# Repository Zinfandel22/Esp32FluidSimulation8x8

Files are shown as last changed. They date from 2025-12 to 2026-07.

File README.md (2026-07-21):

# esp32-s3-flip-fluid-simulation
FLIP (+ PIC) fluid simulation on ESP32-S3 with 8x8 LED matrix display and accelerometer-controlled gravity.

Main objective is to implement a particle-based fluid dynamics simulation using the FLIP method on embedded hardware, exploring the challenges of real-time physics calculations with limited computational resources while creating an interactive, visually appealing display.

## Table of Contents
- [Hardware Components](#hardware-components)
- [Assembly](#assembly)
- [Pinout Configuration](#pinout-configuration)
- [Physical Setup](#physical-setup)
- [Key Features](#key-features)
  - [FLIP Fluid Simulation](#flip-fluid-simulation)
  - [Incompressibility Solver](#incompressibility-solver)
  - [Particle Dynamics Pipeline](#particle-dynamics-pipeline)
  - [Spatial Hash Grid](#spatial-hash-grid)
  - [Bilinear Interpolation](#bilinear-interpolation)
  - [Button Control System](#button-control-system)
  - [Color Presets](#color-presets)
  - [Visualization](#visualization)
  - [Accelerometer Integration](#accelerometer-integration)
- [Technical Specifications](#technical-specifications)
  - [Performance](#performance)
  - [Memory Usage](#memory-usage)
  - [Compiler Optimizations](#compiler-optimizations)
- [Algorithm Details](#algorithm-details)
  - [FLIP Method](#flip-method)
  - [Pressure Projection](#pressure-projection)
  - [Particle Collision](#particle-collision)
- [Build Environment](#build-environment)
- [Configuration Options](#configuration-options)
- [Usage](#usage)
- [Credit](#credit)
- [License](#license)

## Hardware Components
- Waveshare ESP32-S3-Matrix Development Board with 8x8 led matrix and QMI8658 6-Axis IMU (Accelerometer + Gyroscope) integrated
- Momentary Push Button
- Small switch
- TP4057 1A
- 220mAh Lipo pouch battery
hardwareComponents

## Assembly

### Solder de components together using AWG30 wires
guts

### Design and print the casing
casing

### Place the components in casing
gutsincasing

### Finished product
finished2

## Pinout Configuration

### NeoPixel LED Matrix
```cpp
LED_PIN = GPIO 14   // WS2812B data line
NUM_LEDS = 64       // 8x8 matrix
```

### QMI8658 IMU (I2C)
```cpp
SDA_PIN = GPIO 11   // I2C data
SCL_PIN = GPIO 12   // I2C clock
QMI8658_ADDR = 0x6B // I2C device address
I2C_FREQ = 400kHz   // fast mode
```

### Control Button
```cpp
BUTTON_PIN = GPIO 5  // user input (with internal pullup)
```

Button is active low (pressed = LOW, released = HIGH)

## Physical Setup
The simulation uses a 500mm x 500mm virtual container. Particles are constrained inside the solid simulation boundary, and the reachable fluid area is mapped across the full 8x8 LED grid for display. The LED matrix serves as a low-resolution display. The QMI8658 accelerometer continuously updates the gravity direction, allowing the fluid to respond naturally to device orientation.

## Key Features

### FLIP Fluid Simulation

(* means configurable as parameter in config.h)
Particle-In-Cell hybrid method combining Lagrangian particles with Eulerian grid:
- **400 Particles:** hexagonally packed for optimal density, radius = 0.3 * cell_size(*)
- **20x20 Simulation Grid:** provides velocity field for incompressibility solving(*)
- **FLIP/PIC Blending:** 94% FLIP + 6% PIC for stability while preserving momentum(*)
- **Frame Interval:** 23ms real-time (43.5 fps target)(*)
- **Physics Timestep:** 27.6ms simulated time per frame (1.2x speed multiplier snappier fluid motion)(*)
- **Gravity Magnitude:** 9.81 m/s^2, direction updated from accelerometer each frame(*)

### Incompressibility Solver
Iterative pressure projection using Gauss-Seidel with successive over-relaxation:
- **15 Iterations:** balances accuracy vs. computation time (~1.5ms solve time)(*)
- **Over-Relaxation Factor:** 1.9x to accelerate convergence(*)
- **Density Correction:** compensates for particle drift using K-factor = 1.0(configurable)(*)
- **Grid Classification:** cells marked as LIQUID, AIR, or WALL based on particle occupancy

### Particle Dynamics Pipeline
Nine-stage FLIP cycle executed each frame:
1. **Integration:** apply gravity, update positions based on velocity
2. **Separation:** push overlapping particles apart (2 iterations, spatial hash grid)
3. **Collision:** clamp particles inside boundaries with restitution/friction
4. **Grid Preparation:** reset cell types, mark liquid cells, save previous velocities
5. **Particle → Grid Transfer:** scatter particle velocities to grid using bilinear weights
6. **Normalization:** divide accumulated velocities by weights, restore wall velocities
7. **Density Calculation:** compute particle density per cell for drift compensation
8. **Incompressibility Solve:** iteratively adjust velocities to minimize divergence
9. **Grid → Particle Transfer:** interpolate corrected velocities back to particles with FLIP/PIC blending

### Spatial Hash Grid
Efficient particle separation using uniform grid acceleration structure:
- **Cell Spacing:** 2.2 × particle_radius for optimal bucket size
- **Initial Packing:** particles initialized at 1.8 × radius spacing (tighter than 2.0) to increase rest density
- **Collision Detection:** only checks particles in same/adjacent cells (9 cells total)
- **Separation Force:** pushes particles to minimum separation distance
- **Memory Layout:** flat arrays (num_cell_particles, first_cell_particle, cell_particle_ids)
- Significantly faster than O(n²) all-pairs check for 400 particles

### Bilinear Interpolation
Smooth velocity transfers between particles and staggered MAC grid:
- **Staggered Grid:** vx stored on vertical faces, vy on horizontal faces
- **4-Point Weights:** precomputed for each particle based on position
- **Sub-Cell Accuracy:** particles can be anywhere within cell, not just at centers
- **Weight Accumulation:** prevents velocity discontinuities at cell boundaries
- Computed once per particle per transfer, reused for both velocity components

### Button Control System
State machine with debouncing for three interaction types:
- **Single Tap (< 600ms):** cycle through 7 brightness levels (3-13 intensity)(*)
- **Double Tap (< 250ms between):** cycle through 17 color presets (blues, greens, reds, yellows, purples, pinks, white)(*)
- **Long Press (≥ 600ms):** cycle through 5 foam threshold levels (2-30 particle count)(*)
- **Debouncing:** 25ms settling time eliminates mechanical noise(*)
- **NVS Persistence:** settings saved to flash immediately after change, restored on boot

### Color Presets
17 carefully tuned color combinations optimized for LED visibility:
- **Blues/Cyans (4):** pure blue, cyan, sky blue, aqua
- **Greens (2):** lime green, yellow-green
- **Reds (2):** pure red, crimson
- **Oranges/Yellows (3):** orange, golden yellow, amber
- **Purples (3):** violet, lavender, deep purple
- **Pinks/Magentas (2):** hot pink, magenta
- **White (1):** full spectrum white

Each preset is scaled by current brightness setting (0-255 range)

### Visualization
Particle density mapping to LED colors with foam effect:
- **Liquid Rendering:** LEDs with intensity above 2.0 show fluid color at current brightness(*)
- **Foam Effect:** LEDs above the current foam threshold display white at 30% brightness(*)
- **Brightness Scaling:** base color RGB values multiplied by brightness factor (3-13)(*)
- **LED Smoothing:** particles are bilinearly splatted into neighboring LEDs with 0.60 frame persistence(*)
- **Update Rate:** 23ms target frame interval (~43.5 fps), with measured compute headroom up to ~122 fps
- Physical-to-pixel mapping: reachable particle region (meters) -> LED coordinates (0-7)

### Accelerometer Integration
Real-time gravity direction from QMI8658 6-axis IMU:
- **Sensor Mode:** accelerometer only (gyroscope disabled for efficiency)
- **Update Frequency:** every frame (~43 Hz)
- **Range:** ±4g with 8192 LSB/g sensitivity
- **Axis Mapping:** device Y-axis → simulation X (horizontal), device X-axis → simulation Y (vertical)
- **Magnitude:** constant 9.81 m/s², direction varies with tilt
- **Response:** fluid immediately reacts to device orientation changes
- **Calibration:** automatic via sensor hardware, no user calibration needed

## Technical Specifications

### Performance
- **Simulation Grid:** 20x20 cells (400 total)
- **Display Grid:** 8x8 LEDs (64 total, low-resolution fluid projection)
- **Particle Count:** 400 active particles
- **Frame Interval:** 23ms target (43.5 fps)
- **Measured Compute Headroom:** 8.16ms total frame time (~122.5 fps theoretical max)
- **Frame Breakdown:**
  - Integration: ~0.02ms
  - Separation: ~2.40ms
  - Collision: ~0.11ms
  - Grid Prep: ~0.18ms
  - P->G Transfer: ~0.55ms
  - Density: ~0.21ms
  - Solver: ~1.53ms
  - G->P Transfer: ~1.00ms
  - Visualization: ~2.16ms
  - **Total:** ~8.16ms per frame

### Memory Usage
- **Particle Array:** 400 * 16 bytes = 6.4 KB
- **Grid Velocities:** 4 * 400 * 4 bytes = 6.4 KB (current + previous)
- **Weight Accumulators:** 2 * 400 * 4 bytes = 3.2 KB
- **Cell Types:** 400 cells
- **Spatial Hash:** ~9 KB (particle bucketing)
- **Density Array:** 400 * 4 bytes = 1.6 KB
- **Liquid Cell List:** 400 * 4 bytes = 1.6 KB
- **Total:** ~30 KB for the main simulation arrays

### Compiler Optimizations
Aggressive optimization flags for maximum performance:
- **-O3:** maximum optimization level
- **-ffast-math:** aggressive floating-point optimizations (IEEE compliance relaxed)
- **-funroll-loops:** unroll loops for better pipelining
- **-fomit-frame-pointer:** free up register for computations
- **CPU Frequency:** 240 MHz (maximum ESP32-S3 speed)
- **Flash Frequency:** 80 MHz for fast code fetching

## Algorithm Details

Implemented following Ten Minute Physics tutorial closely (https://www.youtube.com/watch?v=XmzBREkK8kY)

### FLIP Method
- **Particles:** carry velocity and position, no pressure field
- **Grid:** solves for incompressibility, enforces boundary conditions
- **Transfer P→G:** particles scatter velocities to grid with bilinear interpolation
- **Solve Pressure:** grid velocities adjusted to satisfy â‹…u = 0
- **Transfer G→P:** particles updated with FLIP/PIC blend:
  - **PIC (6%):** vnew = vgrid (dissipative, stable)
  - **FLIP (94%):** vnew = vold + (vgrid - vgrid_old) (preserves momentum)

### Pressure Projection
- **Divergence Calculation:** sum of velocity flux through cell faces
- **Pressure Gradient:** distributes correction to neighboring cells
- **Over-Relaxation:** scales correction by 1.9x to accelerate convergence
- **Boundary Conditions:** solid walls have zero normal velocity
- **Density Compensation:** adds drift correction term based on particle deficit/surplus

### Particle Collision
Handles boundaries with configurable restitution and friction:
- **Wall Detection:** clamp position one simulation cell plus particle_radius inside the domain
- **Restitution Factor:** 0.2 (20% velocity preserved on bounce)(*)
- **Friction Factor:** 0.2 (20% tangential velocity preserved)(*)
- **Clamping:** prevents particles from penetrating walls
- Applied after position update, before grid transfer

## Build Environment

### PlatformIO Configuration
```ini
[env:esp32-s3-matrix]
platform = espressif32
board = esp32-s3-devkitc-1
framework = arduino

; CRITICAL: Flash configuration for ESP32-S3-Matrix
board_build.flash_mode = dio
board_build.flash_size = 4MB
board_build.partitions = default.csv
board_upload.flash_size = 4MB

; 1. Hardware Accelerations
board_build.f_cpu = 240000000L
board_build.f_flash = 80000000L

build_flags = 
    -DARDUINO_USB_CDC_ON_BOOT=1
    ; compiler optimizations
    -O3
    -ffast-math
    -funroll-loops
    -fomit-frame-pointer
    ; disable debug overhead
    -DCORE_DEBUG_LEVEL=0
    
monitor_speed = 115200
upload_speed = 921600

lib_deps = 
    adafruit/Adafruit NeoPixel@^1.12.0
```

Flash mode and size are pinned explicitly since this board's flash chip isn't always autodetected correctly; the partition table uses PlatformIO's standard `default.csv` scheme.

## Configuration Options

All simulation parameters can be adjusted in `config.h`:

### Physics Constants
```cpp
GRAVITY_MAGNITUDE = 9.81f          // m/s²
FRAME_INTERVAL = 0.023f            // base timestep
SPEED_MULTIPLIER = 1.2f            // time acceleration
FLIP_RATIO = 0.94f                 // FLIP vs PIC blend
INCOMPRESSIBILITY_ITERATIONS = 15  // solver iterations
OVERRELAXATION = 1.9f              // convergence acceleration
```

### Particle Settings
```cpp
NUM_PARTICLES = 400                // total particle count
RESTITUTION_FACTOR = 0.2f          // bounce coefficient
FRICTION_FACTOR = 0.2f             // wall friction
```

### Grid Resolution
```cpp
GRID_SIZE_X = 20                   // simulation cells
GRID_SIZE_Y = 20
PHYSICAL_WIDTH = 0.5f              // meters
PHYSICAL_HEIGHT = 0.5f
```

### Visualization
```cpp
PARTICLE_THRESHOLD = 2.0f          // min LED intensity for liquid color
LED_PERSISTENCE = 0.60f            // display smoothing decay
// Foam thresholds: 30, 5, 4, 3, 2  // configured in button presets
```

## Usage

### First Boot
1. Device initializes with default settings (blue color, low brightness, low foam)
2. Particles appear in block formation at bottom of display
3. Tilt device to control gravity direction - fluid responds immediately
### Test

https://github.com/user-attachments/assets/9a86d0c9-9984-4224-b226-0375ce9b3e63

### Button Controls
- **Single Tap:** cycle brightness (3 → 4 → 5 → 6 → 9 → 11 → 13 → 3...)
- **Double Tap:** cycle colors (blue → cyan → green → red → orange → purple → pink → white → blue...)
- **Long Press:** cycle foam threshold (none → low → medium → high → max → none...)
### Button funcionality test

https://github.com/user-attachments/assets/5af7af76-c64d-4482-b536-27835820dfac

### Settings Persistence
All button settings automatically save to flash and restore on next power-up.

## Credit

- MAtthias Müller´s Ten Minute Physics: "18 - How to write a FLIP water / fluid simulation running in your browser"
- https://www.youtube.com/watch?v=XmzBREkK8kY

## License
MIT License - feel free to use, modify, and distribute.

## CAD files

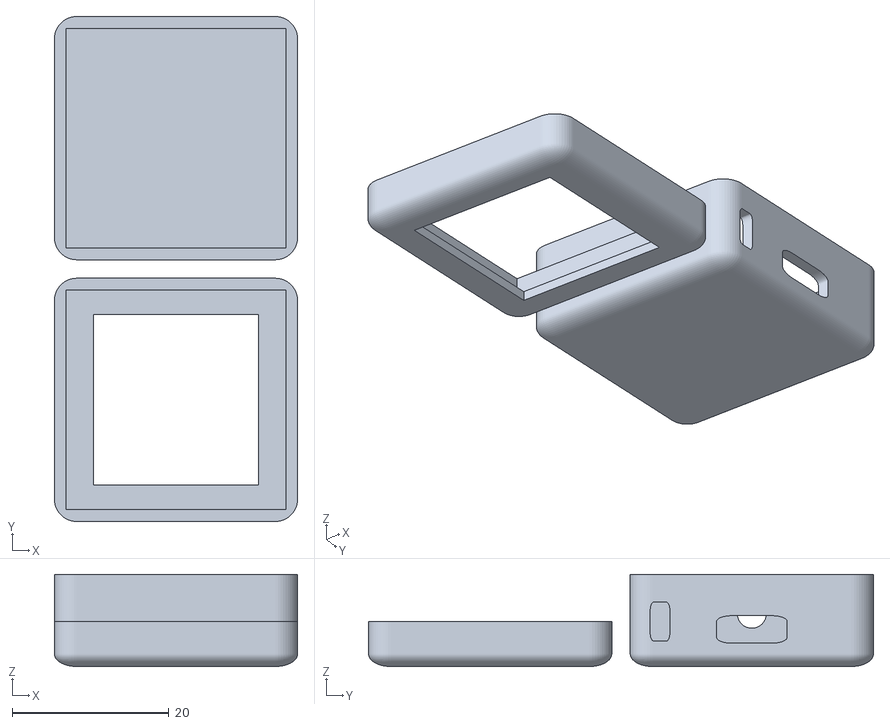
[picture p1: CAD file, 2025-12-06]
Casing and box/2D8x8fluidcasing.stl
31.0 x 64.3 x 11.7

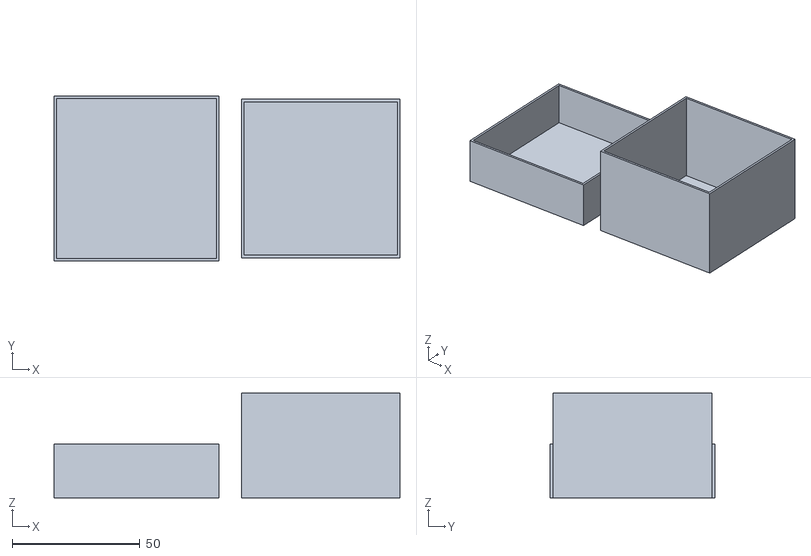
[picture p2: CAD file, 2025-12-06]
Casing and box/giftbox.stl
135.2 x 64.5 x 41.0

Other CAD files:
Casing and box/2D8x8fluidcasing.blend
Casing and box/giftbox.blend

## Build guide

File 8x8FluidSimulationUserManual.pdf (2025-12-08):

# 8×8 LED Matrix Mini Fluid Simulation Gadget

## User Manual

## Device Overview

FLIP Fluid Simulator with a real-time physics simulation displayed on a 64-LED matrix (8×8 grid) at ~43 FPS (23ms per frame). The built-in accelerometer allows the fluid to respond to device tilting.

## Button Controls

The device features a single button with three press patterns:

Gesture | Action
Single Press | Cycle through 7 brightness levels (3, 4, 5, 6, 9, 11, 13)
Double-Press | Cycle through 17 color presets (blues, greens, reds, oranges, yellows, purples, pinks, white)
Long Press | Hold 600ms to cycle foam effect threshold (5 levels)

Note: Colors are mixed from RGB (0–255) then compressed to brightness level. Some colors may look identical at low brightness (e.g. at level 3: BLUE1 (0,0,255) → (0,0,3) and PURPLE1 (60,0,255) → (0,0,3)).

## Technical Specifications

Component | Specification
Microcontroller | ESP32-S3 @ 240MHz
Display | 64 RGB LEDs (8×8 matrix, WS2812B)
Accelerometer | QMI8658 6-axis IMU
Power | 220mAh LiPo battery

# Open Source Project

Full source code available at:

### github.com/vateva/Esp328x8fluid

Built with:
ESP32-S3 | FreeRTOS | C/C++ | FLIP Fluid Simulation
QMI8658 IMU | WS2812B LED Matrix

© 2025 - Open Source Hardware & Software Licensed under MIT License

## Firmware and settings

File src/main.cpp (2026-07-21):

#include "config.h"
#include "grid.h"
#include "particle.h"
#include "utils.h"
#include "button.h"

#include <WiFi.h>
#include <esp_bt.h>
#include <esp_wifi.h>

#include "esp_sleep.h"

// global instances
Adafruit_NeoPixel matrix = Adafruit_NeoPixel(NUM_LEDS, LED_PIN, NEO_RGB + NEO_KHZ800);
Grid grid;                         // single grid instance for the simulation
Particle particles[NUM_PARTICLES]; // array of all particles
ButtonHandler button;              // button

// timing control for fixed timestep
unsigned long lastStepTime = 0;

// gravity vector (updated from accelerometer each frame)
float gravityX = 0.0f;
float gravityY = -GRAVITY_MAGNITUDE; // default: pointing down
float currentAccelZ = 0.0f;          // ADD THIS: To track face-down state

// particle radius - calculated from cell size like reference code
float particleRadius = 0.0f;

// LED intensity buffers. Particles are splatted into the 8x8 display with
// bilinear weights, then lightly decayed to hide 8x8 quantization.
float ledIntensity[NUM_LEDS] = {0.0f};
float ledNextIntensity[NUM_LEDS] = {0.0f};

// --- Profiling Variables (Time in milliseconds) ---
float t_integrate = 0; // Movement & Gravity
float t_push = 0;      // Particle Separation (Heavy)
float t_collision = 0; // Wall handling
float t_grid_prep = 0; // Resetting/Clearing grid
float t_p2g = 0;       // Particle -> Grid Transfer
float t_density = 0;   // Density calculation
float t_solve = 0;     // Incompressibility (Heavy)
float t_g2p = 0;       // Grid -> Particle Transfer
float t_vis = 0;       // LED Visualization

void enterSleepMode()
{
  Serial.println("Entering low power sleep mode...");

  // Turn off the LEDs
  matrix.clear();
  matrix.show();

  // Configure the button to wake the ESP32 (Replace BUTTON_PIN if named differently in config.h)
  gpio_wakeup_enable((gpio_num_t)BUTTON_PIN, GPIO_INTR_LOW_LEVEL);
  esp_sleep_enable_gpio_wakeup();

  // Pause the CPU and enter Light Sleep
  esp_light_sleep_start();

  // --- SYSTEM WAKES UP HERE ---
  Serial.println("Waking up!");

  // Reset the simulation timer so the physics engine resumes smoothly
  lastStepTime = millis();
}

// function to initialize particles in a block formation
void initializeParticles()
{
  float cell_size_x = PHYSICAL_WIDTH / GRID_SIZE_X;
  float cell_size_y = PHYSICAL_HEIGHT / GRID_SIZE_Y;
  float cell_size = (cell_size_x > cell_size_y) ? cell_size_x : cell_size_y;

  particleRadius = 0.3f * cell_size;

  float dx = 1.8f * particleRadius;
  float dy = sqrtf(3.0f) / 2.0f * dx;

  float available_width = PHYSICAL_WIDTH - 2.0f * cell_size - 2.0f * particleRadius;
  float available_height = PHYSICAL_HEIGHT - 2.0f * cell_size - 2.0f * particleRadius;

  int particles_per_row = (int)(available_width / dx);
  int particles_per_col = (int)(available_height / dy);

  while (particles_per_row * particles_per_col > NUM_PARTICLES)
  {
    if (particles_per_row > particles_per_col)
    {
      particles_per_row--;
    }
    else
    {
      particles_per_col--;
    }
  }

  float start_x = cell_size + particleRadius;
  float start_y = cell_size + particleRadius;

  int particle_index = 0;
  for (int j = 0; j < particles_per_col && particle_index < NUM_PARTICLES; j++)
  {
    for (int i = 0; i < particles_per_row && particle_index < NUM_PARTICLES; i++)
    {
      float offset = (j % 2 == 0) ? 0.0f : particleRadius;

      particles[particle_index].x_pos = (start_x + i * dx + offset);
      particles[particle_index].y_pos = (start_y + j * dy);
      particles[particle_index].vx = (0.0f);
      particles[particle_index].vy = (0.0f);
      particle_index++;
    }
  }

  while (particle_index < NUM_PARTICLES)
  {
    particles[particle_index].x_pos = (start_x);
    particles[particle_index].y_pos = (start_y);
    particles[particle_index].vx = (0.0f);
    particles[particle_index].vy = (0.0f);
    particle_index++;
  }

  Serial.print("Particle radius: ");
  Serial.print(particleRadius * 1000.0f, 3);
  Serial.println(" mm");
  Serial.print("Particles arranged: ");
  Serial.print(particles_per_row);
  Serial.print(" x ");
  Serial.println(particles_per_col);
}

// function to map particles to led matrix and display with dynamic vector-product gradient
void visualizeParticles()
{
  const float cell_size_x = PHYSICAL_WIDTH / GRID_SIZE_X;
  const float cell_size_y = PHYSICAL_HEIGHT / GRID_SIZE_Y;
  const float render_min_x = cell_size_x + particleRadius;
  const float render_min_y = cell_size_y + particleRadius;
  const float render_max_x = PHYSICAL_WIDTH - cell_size_x - particleRadius;
  const float render_max_y = PHYSICAL_HEIGHT - cell_size_y - particleRadius;

  // 8x8 scales map coordinates explicitly from 0.0f to 7.0f
  const float led_scale_x = 7.0f / (render_max_x - render_min_x);
  const float led_scale_y = 7.0f / (render_max_y - render_min_y);

  for (int i = 0; i < NUM_LEDS; i++)
  {
    ledNextIntensity[i] = 0.0f;
  }

  // Bilinear splatting into 8x8 matrix grid
  for (int i = 0; i < NUM_PARTICLES; i++)
  {
    float fx = (particles[i].x_pos - render_min_x) * led_scale_x;
    float fy = (particles[i].y_pos - render_min_y) * led_scale_y;

    fx = utils::clamp(fx, 0.0f, 7.0f);
    fy = utils::clamp(fy, 0.0f, 7.0f);

    int x0 = (int)fx;
    int y0 = (int)fy;
    int x1 = (x0 < 7) ? x0 + 1 : x0;
    int y1 = (y0 < 7) ? y0 + 1 : y0;

    float tx = fx - x0;
    float ty = fy - y0;
    float sx = 1.0f - tx;
    float sy = 1.0f - ty;

    ledNextIntensity[y0 * 8 + x0] += sx * sy;
    ledNextIntensity[y0 * 8 + x1] += tx * sy;
    ledNextIntensity[y1 * 8 + x1] += tx * ty;
    ledNextIntensity[y1 * 8 + x0] += sx * ty;
  }

  uint8_t base_r, base_g, base_b;
  button.getCurrentColorRGB(&base_r, &base_g, &base_b);
  int brightness = button.getCurrentBrightness();

  uint8_t scaled_r = (base_r * brightness) / 255;
  uint8_t scaled_g = (base_g * brightness) / 255;
  uint8_t scaled_b = (base_b * brightness) / 255;

  int foam_threshold = button.getCurrentFoamThreshold();

  // turn on LEDs with scaled colors
  for (int i = 0; i < NUM_LEDS; i++) {
    float previous = ledIntensity[i] * 0.72f;
    float current = ledNextIntensity[i];
    ledIntensity[i] = (current > previous) ? current : previous;

      if (ledIntensity[i] > PARTICLE_THRESHOLD)
      {
        float amount = utils::clamp(ledIntensity[i] / (PARTICLE_THRESHOLD * 2.5f), 0.25f, 1.0f);

        // Map pixel coordinates relative to the 8x8 space center (from -3.5 to +3.5)
        float px = x - 3.5f;
        float py = y - 3.5f;

        // Vector dot product: projects pixel position along the current gravity pull
        float dot_product = px * nx + py * ny;
        float wave_phase = dot_product * 0.22f;

        // Check if the button color is set to White (usually the trigger for Rainbow Mode)
        bool isRainbowMode = (base_r > 240 && base_g > 240 && base_b > 240);

        uint8_t final_r, final_g, final_b;

        if (isRainbowMode)
        {
          // ==========================================
          // MODE 1: Spectral Vector Rainbow
          // ==========================================
          float r_coeff = sinf(wave_phase) * 0.5f + 0.5f;
          float g_coeff = sinf(wave_phase + 2.0944f) * 0.5f + 0.5f;
          float b_coeff = sinf(wave_phase + 4.1888f) * 0.5f + 0.5f;

          final_r = (uint8_t)(brightness * amount * r_coeff);
          final_g = (uint8_t)(brightness * amount * g_coeff);
          final_b = (uint8_t)(brightness * amount * b_coeff);
        }
        else
        {
          // ==========================================
          // MODE 2: Dynamic Solid Colors (From Double Tap)
          // ==========================================
          // Create a natural light/dark shading wave based on gravity pull
          float shading = sinf(wave_phase) * 0.4f + 0.6f;

          // Mix the button's RGB color with the master brightness, particle amount, and shading
          final_r = (uint8_t)((base_r * brightness / 255.0f) * amount * shading);
          final_g = (uint8_t)((base_g * brightness / 255.0f) * amount * shading);
          final_b = (uint8_t)((base_b * brightness / 255.0f) * amount * shading);
        }

        matrix.setPixelColor(i, matrix.Color(final_r, final_g, final_b));
      }
      else if (ledIntensity[i] >= foam_threshold)
      {
        uint8_t foam = (uint8_t)(0.3f * brightness);
        matrix.setPixelColor(i, matrix.Color(foam, foam, foam));
      }
      else
      {
        matrix.setPixelColor(i, matrix.Color(0, 0, 0));
      }
    }
  }

  matrix.show();
}

// read accelerometer and update gravity direction
void updateGravityFromSensor()
{
  float accelX, accelY, accelZ;
  utils::readQMI8658Accel(&accelX, &accelY, &accelZ);

  gravityX = -accelY * GRAVITY_MAGNITUDE;
  gravityY = accelX * GRAVITY_MAGNITUDE;

  // Save the Z-axis reading globally
  currentAccelZ = accelZ;
}

// execute one complete flip timestep with profiling
void runFLIPStep()
{
  unsigned long t0 = micros();

  for (int i = 0; i < NUM_PARTICLES; i++)
  {
    particles[i].addGravity(gravityX, gravityY);
    particles[i].updatePosition();
  }
  unsigned long t1 = micros();

  grid.pushParticlesApart(particles, NUM_PARTICLES, 2);
  unsigned long t2 = micros();

  for (int i = 0; i < NUM_PARTICLES; i++)
  {
    grid.handleParticleCollision(&particles[i]);
  }
  unsigned long t3 = micros();

  grid.resetCellTypesToAir();
  for (int i = 0; i < NUM_PARTICLES; i++)
  {
    grid.markCellWithLiquid(&particles[i]);
  }

  grid.savePreviousVelocities();
  grid.clearVelocitiesAndWeights();
  unsigned long t4 = micros();

  for (int i = 0; i < NUM_PARTICLES; i++)
  {
    grid.transferVelocityfromParticleToGrid(&particles[i]);
  }
  grid.normalizeGridVelocities();
  grid.restoreSolidCellVelocities();
  unsigned long t5 = micros();

  grid.updateParticleDensity(particles, NUM_PARTICLES);
  grid.savePreviousVelocities();
  unsigned long t6 = micros();

  grid.forcingIncompressibility();
  unsigned long t7 = micros();

  for (int i = 0; i < NUM_PARTICLES; i++)
  {
    grid.transferVelocityfromGridToParticle(&particles[i]);
  }
  unsigned long t8 = micros();

  t_integrate = (t1 - t0) / 1000.0f;
  t_push = (t2 - t1) / 1000.0f;
  t_collision = (t3 - t2) / 1000.0f;
  t_grid_prep = (t4 - t3) / 1000.0f;
  t_p2g = (t5 - t4) / 1000.0f;
  t_density = (t6 - t5) / 1000.0f;
  t_solve = (t7 - t6) / 1000.0f;
  t_g2p = (t8 - t7) / 1000.0f;
}

void setup()
{
  Serial.begin(115200);
  delay(1000);

  WiFi.mode(WIFI_OFF);
  btStop();
  esp_wifi_stop();
  esp_bt_controller_disable();

  setCpuFrequencyMhz(240);

  Serial.println("\n\n================================");
  Serial.println("FLIP Fluid Simulation - ESP32-S3 (8x8)");
  Serial.println("================================\n");

  matrix.begin();
  matrix.clear();
  matrix.show();

  Serial.println("Initializing button...");
  button.init();

  Wire.begin(SDA_PIN, SCL_PIN);
  Wire.setClock(400000);
  delay(100);

  Serial.println("Initializing QMI8658 sensor...");
  if (!utils::initQMI8658())
  {
    Serial.println("ERROR: QMI8658 initialization failed!");
    while (1)
    {
      matrix.clear();
      for (int i = 0; i < 8; i++)
      {
        matrix.setPixelColor(i * 9, matrix.Color(50, 0, 0));
      }
      matrix.show();
      delay(500);
      matrix.clear();
      matrix.show();
      delay(500);
    }
  }
  Serial.println("QMI8658 initialized successfully!");

  Serial.println("Initializing particles...");
  initializeParticles();
  Serial.print("Created ");
  Serial.print(NUM_PARTICLES);
  Serial.println(" particles");

  Serial.println("Initializing spatial hash grid...");
  grid.initParticleSpatialHash(NUM_PARTICLES, particleRadius);
  grid.markCellWalls();

  Serial.println("\n=== Configuration ===");
  Serial.printf("Grid size: %d x %d\n", GRID_SIZE_X, GRID_SIZE_Y);
  Serial.printf("Physical size: %.2f x %.2f mm\n", PHYSICAL_WIDTH * 1000.0f, PHYSICAL_HEIGHT * 1000.0f);
  Serial.printf("Timestep: %.1f ms\n", DELTA_T * 1000.0f);
  Serial.printf("Target FPS: %.1f\n", 1.0f / DELTA_T);
  Serial.printf("FLIP ratio: %.2f\n", FLIP_RATIO);
  Serial.printf("Incompressibility iterations: %d\n", INCOMPRESSIBILITY_ITERATIONS);

  Serial.println("\n=== Starting simulation ===");
  lastStepTime = millis();
}

void loop()
{
  unsigned long currentTime = millis();
  const unsigned long stepInterval = (unsigned long)(FRAME_INTERVAL * 1000.0f);
  static unsigned long accumulatedTime = 0;
  const unsigned long maxFrameCatchup = stepInterval * 2;

  button.update();

  // --- Face-Down Sleep Timer Logic ---
  static unsigned long faceDownStartTime = 0;
  static bool isFaceDown = false;

  // Check if Z-axis indicates face-down.
  // Depending on how your IMU chip is mounted, face-down will either be < -0.8f or > 0.8f.
  // If it goes to sleep while face-UP, simply change this to: (currentAccelZ > 0.8f)
  Serial.printf("Current Z-axis: %.3f\n", currentAccelZ);
  if (currentAccelZ > 0.2f)
  {
    if (!isFaceDown)
    {
      isFaceDown = true;
      faceDownStartTime = millis(); // Start the 3-second stopwatch
      Serial.println("Face down detected - starting sleep timer...");
    }
    else if (millis() - faceDownStartTime >= 3000)
    {
      // 3 seconds have passed! Go to sleep.
      enterSleepMode();
      isFaceDown = false; // Reset state when we wake back up
    }
  }
  else
  {
    // We picked it up before 3 seconds finished, cancel the timer.
    if (isFaceDown)
    {
      isFaceDown = false;
      Serial.println("Sleep timer canceled.");
    }
  }

  accumulatedTime += currentTime - lastStepTime;
  lastStepTime = currentTime;
  if (accumulatedTime > maxFrameCatchup)
  {
    accumulatedTime = maxFrameCatchup;
  }

  if (accumulatedTime >= stepInterval)
  {
    accumulatedTime -= stepInterval;

    updateGravityFromSensor();
    runFLIPStep();

    unsigned long t_vis_start = micros();
    visualizeParticles();
    t_vis = (micros() - t_vis_start) / 1000.0f;

    static unsigned long lastPrintTime = 0;
    if (currentTime - lastPrintTime > 10000)
    {
      float total_ms = t_integrate + t_push + t_collision + t_grid_prep + t_p2g + t_density + t_solve + t_g2p + t_vis;
      float max_fps = 1000.0f / total_ms;

      Serial.println("\n--- Performance Stats ---");
      Serial.printf("Total Frame Time: %.2f ms | Max FPS: %.1f\n", total_ms, max_fps);
      Serial.println("Breakdown:");
      Serial.printf("  1. Integrate: %.2f ms\n", t_integrate);
      Serial.printf("  2. Separation:%.2f ms\n", t_push);
      Serial.printf("  3. Collision: %.2f ms\n", t_collision);
      Serial.printf("  4. Grid Prep: %.2f ms\n", t_grid_prep);
      Serial.printf("  5. P -> G:    %.2f ms\n", t_p2g);
      Serial.printf("  6. Density:   %.2f ms\n", t_density);
      Serial.printf("  7. Solver:    %.2f ms\n", t_solve);
      Serial.printf("  8. G -> P:    %.2f ms\n", t_g2p);
      Serial.printf("  9. Visualize: %.2f ms\n", t_vis);

      lastPrintTime = currentTime;
    }
  }
}

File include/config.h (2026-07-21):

// config.h
#ifndef CONFIG_H
#define CONFIG_H

#include <Adafruit_NeoPixel.h>
#include <Arduino.h>
#include <Wire.h>

// LED Matrix Configuration
#define LED_PIN 14
#define NUM_LEDS 64
//#define BRIGHTNESS 5 configurable in button

// QMI8658 Configuration
#define QMI8658_ADDR 0x6B
#define SDA_PIN 11
#define SCL_PIN 12

// QMI8658 Registers
#define QMI8658_WHO_AM_I 0x00
#define QMI8658_CTRL1 0x02
#define QMI8658_CTRL2 0x03
#define QMI8658_CTRL3 0x04
#define QMI8658_CTRL7 0x08
#define QMI8658_ACC_X_L 0x35
//#define QMI8658_GYR_X_L 0x3B
//#define QMI8658_TEMP_L 0x33

//button
#define BUTTON_PIN 0

// timing thresholds in milliseconds
#define DEBOUNCE_TIME 25
#define LONG_PRESS_THRESHOLD 600
#define DOUBLE_TAP_WINDOW 250

// NVS namespace for storing settings
#define NVS_NAMESPACE "fluid_settings"
#define NVS_KEY_COLOR "color"
#define NVS_KEY_BRIGHTNESS "brightness"
#define NVS_KEY_FOAM "foam"

//------simulation constants------

// general
#define GRAVITY_MAGNITUDE 9.81f                      // gravity magnitude in m/s^2
#define FRAME_INTERVAL 0.023f                        // real time between frames
#define SPEED_MULTIPLIER 1.2f                        // adjust this to control speed
#define DELTA_T (FRAME_INTERVAL * SPEED_MULTIPLIER)  // physics timestep
#define FLIP_RATIO 0.94f                             // flip vs pic ratio
#define INCOMPRESSIBILITY_ITERATIONS 15              // number of incompressibility iterations
#define OVERRELAXATION 1.9f                          // overrelaxation factor to speed up convergence
#define K_FACTOR 1.0f                                // stiffness factor for density correction

// particles
#define NUM_PARTICLES 400  // number of fluid particles
#define RESTITUTION_FACTOR 0.2f//percentaje of velocity perserved when bouncing off a wall
#define FRICTION_FACTOR 0.2f // percentaje of conserved velocity in direction of wall

// grid
#define GRID_SIZE_X 20  // grid cells in x direction
#define GRID_SIZE_Y 20 // grid cells in y direction

// physical dimensions of led matrix in meters
#define PHYSICAL_WIDTH 0.5f
#define PHYSICAL_HEIGHT 0.5f

// visualization
#define PARTICLE_THRESHOLD 2.0f
#define LED_PERSISTENCE 0.60f
//#define PARTICLE_THRESHOLD_FOAM 5.0f  configurable with the button

#endif

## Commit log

2025-11-30 fixed bug, wasnt saving previous velocities before forcing incompressibility
    [config.h, main.cpp]
2025-11-30 fixed some doubles to float
    [config.h, main.cpp]
2025-11-30 inlined inversefastsqrt and clamp functions in utils.h
2025-12-02 added branchless clamp
2025-12-04 added button for basic configuration
2025-12-06 Add README for ESP32-S3 FLIP fluid simulation
    Added detailed documentation for the ESP32-S3 FLIP fluid simulation project, including hardware components, assembly instructions, pinout configuration, features, technical specifications, and usage guidelines.
2025-12-06 added stl and blender files of the casing and box
    [2D8x8fluidcasing.blend, 2D8x8fluidcasing.stl, giftbox.blend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]
2026-07-20 Tune FLIP ratio, expose LED persistence as config, sync README
    [config.h, main.cpp]
2026-07-21 Added power down functionality when the device is faced down
